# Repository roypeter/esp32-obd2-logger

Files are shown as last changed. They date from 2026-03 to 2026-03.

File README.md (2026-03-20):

# ESP32 OBD2 CAN Logger

A DIY OBD2 data logger built with an ESP32. Reads live engine data over CAN bus, logs to CSV (SD card or internal flash), shows live values on a small OLED display, and serves a real-time web dashboard over WiFi.

> **Note:** Only tested on a **2020 Tata Nexon 1.2L Turbo Petrol (6-speed manual)**. Should work on any car with standard OBD2 over CAN (ISO 15765-4, 500 kbps).

## Using AI to review your driving data

Download the CSV from the WiFi dashboard and upload it to an AI model like **Claude** or **Gemini Pro**. You can ask questions like:

- "How is the turbo performance?"
- "Review if all sensors are working correctly and flag any issues"
- "Is the fuel trim normal or is the engine running rich/lean?"
- "Any signs of engine problems based on this data?"

The AI can analyze thousands of rows of sensor data in seconds and give you a plain-English health report of your car.

Here's an example report generated from a real driving session:

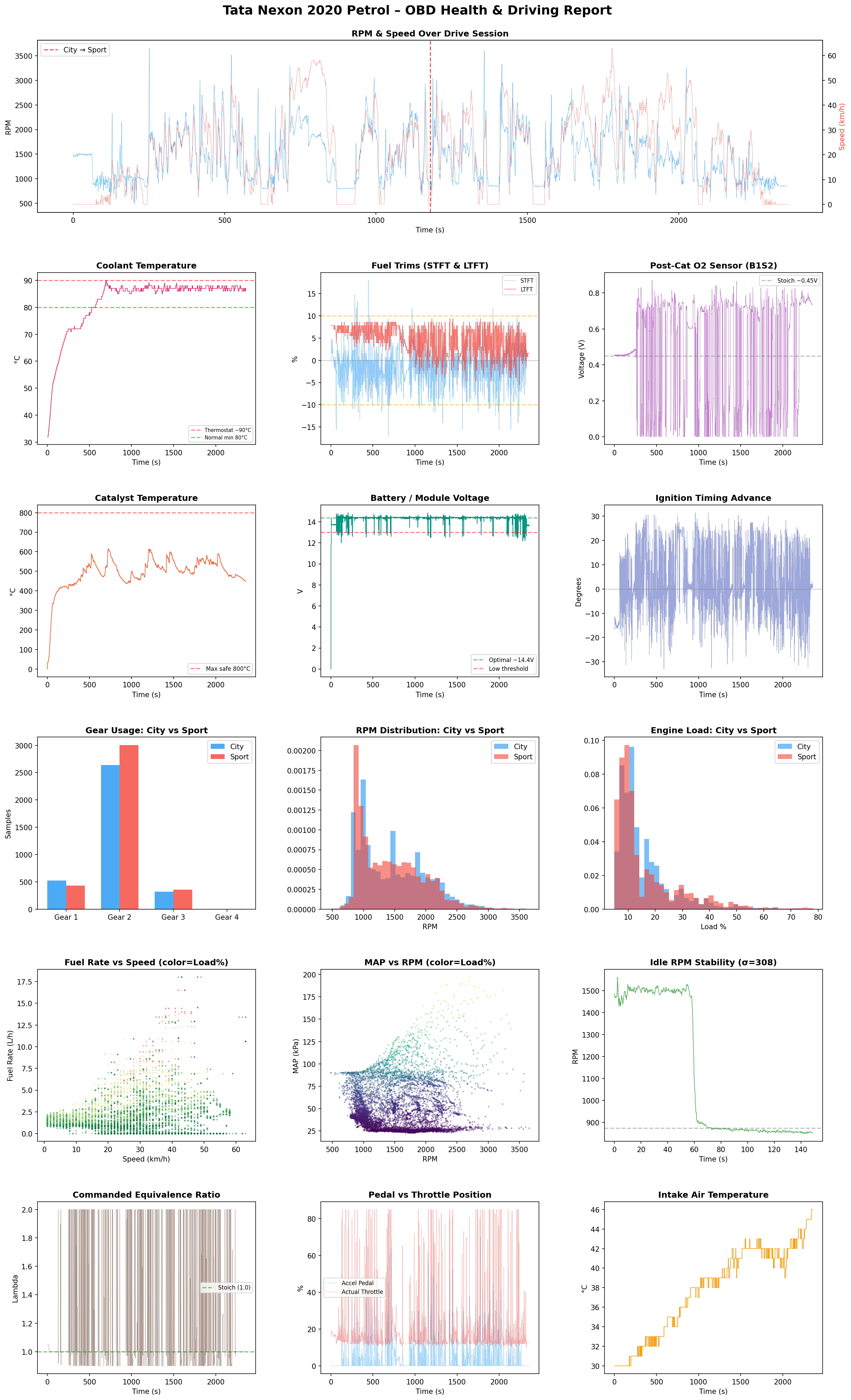
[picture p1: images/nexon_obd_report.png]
OBD Health & Driving Report


## What it does

- Reads **30+ OBD2 PIDs**: RPM, speed, coolant temp, oil temp, MAP, IAT, engine load, timing advance, throttle, accelerator pedal, fuel trims, O2 sensors, catalyst temp, fuel rate, voltage, and more
- **Logs to CSV** at ~4 Hz with automatic session numbering — SD card preferred, falls back to ESP32 internal flash (LittleFS) if no SD card is present
- **OLED display** (optional) — rotates between live data, running averages, and session stats (max boost, trip distance, fuel economy)
- **WiFi dashboard** — connect your phone to see live gauges, download CSV files, and check PID status
- **Smart polling** — fast-changing PIDs polled at ~4 Hz, slow-changing PIDs at ~1 Hz
- **Auto-disables unsupported PIDs** — if a PID times out 10 times in a row, it stops polling it
- **Estimates current gear** from RPM/speed ratio (calibrated for Nexon 6MT gearbox)

## Parts list

| Part | Notes |
|---|---|
| [ESP32 Dev Board](https://robocraze.com/products/esp32-development-board) | Any ESP32-WROOM-32 dev board works |
| [TJA1050 CAN Module](https://robu.in/product/tja1050-can-module-green-board/) | 5V module — needs a voltage divider on RX (see wiring). A 3.3V CAN module (e.g. SN65HVD230) is easier if you can find one |
| [Micro SD Card Module](https://robu.in/product/micro-sd-card-module/) *(optional)* | HW-125 with onboard level shifter. Power from 5V. Without it, logs to ESP32 internal flash (~1.5 MB) |
| [0.96" SSD1306 OLED Display](https://robu.in/product/0-96-oled-display-module-spi-i2c-128x64-7-pin-blue/) *(optional)* | 128x64, I2C. The logger works without it |
| [OBD2 Extension Cable](https://www.amazon.in/dp/B0F6NGFKQT) | 16-pin male to female — splice into the male end for CAN High/Low |
| SD Card *(optional)* | I use a SanDisk Ultra 64GB. Any size works — CSV files are small |
| Jumper wires, solder, etc. | -- |

I mostly order from [robocraze.com](https://robocraze.com) or [robu.in](https://robu.in) — check both for availability and pricing.

## Wiring

Full wiring details below.

### ESP32 to TJA1050 CAN Module

```
ESP32 GPIO5  ──────────────────  TJA1050 TXD
ESP32 GPIO4  ──┬── 1kΩ ────────  TJA1050 RXD     (voltage divider: 5V → 3.4V)
               └── 2.2kΩ ─────  GND
ESP32 5V     ──────────────────  TJA1050 VCC
ESP32 GND    ──────────────────  TJA1050 GND
```

> If using a 3.3V CAN transceiver (e.g. SN65HVD230), skip the voltage divider and connect RX directly.

### TJA1050 to OBD2 Connector

```
TJA1050 CANH  ──  OBD2 Pin 6  (CAN High)
TJA1050 CANL  ──  OBD2 Pin 14 (CAN Low)
TJA1050 GND     ──  OBD2 Pin 4 or 5  (Chassis/Signal Ground)
```

### ESP32 to SD Card Module (HW-125) — optional

```
ESP32 GND    ──  GND
ESP32 5V     ──  VCC
ESP32 GPIO19 ──  MISO
ESP32 GPIO23 ──  MOSI
ESP32 GPIO18 ──  SCK
ESP32 GPIO15 ──  CS
```

> If no SD card module is connected, the logger automatically falls back to the ESP32's internal flash (LittleFS, ~1.5 MB). This gives you roughly 30 minutes of logging. Download the CSV over WiFi before it fills up.

### ESP32 to OLED Display (optional)

```
ESP32 GND    ──  GND
ESP32 3.3V   ──  VCC
ESP32 GPIO21 ──  SDA
ESP32 GPIO22 ──  SCL
```

## Flashing

### Prerequisites

1. Install the [Arduino IDE](https://www.arduino.cc/en/software) (v2.x recommended)
2. Add ESP32 board support:
   - Go to **Tools → Board → Boards Manager**, search "esp32", install **esp32 by Espressif Systems**
3. Install required libraries via **Sketch → Include Library → Manage Libraries**:
   - `Adafruit SSD1306`
   - `Adafruit GFX Library`

   (SD, SPI, Wire, WiFi, and WebServer are included with the ESP32 board package.)

### Upload

1. Connect the ESP32 via USB
2. Open `main/main.ino` in Arduino IDE
3. Select your board: **Tools → Board → ESP32 Dev Module**
4. Select the correct port: **Tools → Port**
5. Click **Upload**

## Usage

### 1. Power up

Plug the ESP32 into the car's USB port (or a USB power bank for bench testing). The OBD2 extension cable connects to the car's OBD2 port under the dashboard.

On startup, the OLED (if connected) shows:
```
Nexon CAN Logger

SD  Session #1            (or "LittleFS  Session #1" if no SD card)
Total: 59000 MB
Used:  12 MB
Free:  58988 MB
```

The serial monitor (115200 baud) shows the same info plus CAN bus init status.

### 2. Connect to the WiFi dashboard

1. On your phone, connect to WiFi network: **`obd2logger`** (password: `logger@ka01`)
2. Open a browser and go to **`http://192.168.4.1`**

You'll see a live dashboard with all the gauges updating every second:

- **Dashboard** (`/`) — live gauges for all PIDs, storage bar, download/session links
- **All Sessions** (`/sessions`) — list of all logged sessions with download and delete options
- **Download Current** (`/download`) — download the active session CSV
- **Debug Log** (`/log`) — ring buffer of recent debug messages
- **PID Status** (`/timeouts`) — see which PIDs are responding and which got auto-disabled

### 3. Data logging

Logging starts automatically on boot. Each power cycle creates a new session file (`s001.csv`, `s002.csv`, ...). With an SD card, files are stored in `/data/` on the card. Without one, they go to the ESP32's internal flash (LittleFS).

CSV columns:
```
Timestamp_ms, RPM, Speed_kmh, Coolant_C, OilTemp_C, MAP_kPa, IAT_C,
Load_pct, TimingAdv_deg, Throttle_pct, AccelPedal_pct, CmdThrottle_pct,
DemandTorque_pct, ActualTorque_pct, STFT_pct, LTFT_pct, Baro_kPa,
O2S2_V, O2S2_STFT_pct, CmdEquivRatio, CatalystTemp_C, O2_SecLTFT_pct,
Gear, FuelLevel_pct, FuelRate_Lph, ModuleVoltage_V, AmbientTemp_C,
RefTorque_Nm, O2S1_Lambda, O2S1_Current_mA, AbsLoad_pct, EvapPurge_pct
```

### 4. Serial monitor output

At 115200 baud, you'll see a continuous stream like:
```
RPM:850 Spd:0 Clt:82 Oil:78 MAP:33 IAT:42 Load:18% Tmg:6.5 Thr:14% ...
```

Plus periodic status:
```
[12345] TX:482 RX:391 RX_timeout:91
[12345] TWAI state:1 txErr:0 rxErr:0 txQ:0 rxQ:0
```

## Notes

- **SD card is optional.** If no SD card is found, the logger falls back to ESP32 internal flash (LittleFS, ~1.5 MB). That's roughly 30 minutes of logging at 4 Hz — download the CSV over WiFi before it fills up. If neither SD nor LittleFS can mount, the ESP32 won't start (nothing to log to).
- **OLED is optional.** If not connected, everything else works normally.
- **Not all PIDs will work on every car.** The logger auto-disables PIDs that your car's ECU doesn't support. Check the PID Status page (`/timeouts`) to see which ones your car responds to.
- **Gear estimation** is calibrated for the Nexon 1.2T 6-speed manual gearbox. If you're using a different car, you'll need to adjust the `GEAR_RATIO_MIN[]` and `GEAR_RATIO_MAX[]` arrays in the code.
- **WiFi range** is limited to a few meters — it's meant for use inside the car.

## 3D Printable Cases

If you are looking to enclose your logger components, check out the [3D Printable Cases](3dprint/README.md) provided in the `3dprint` folder. It includes basic housings for the ESP32, S3 module, and OLED display.

## License

This project is licensed under [CC BY-NC 4.0](https://creativecommons.org/licenses/by-nc/4.0/) — free to use, share, and modify for non-commercial purposes with attribution. No warranty.

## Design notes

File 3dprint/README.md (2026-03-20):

# 3D Printable Cases

These are 3D printable cases for:
- Housing both the ESP32 dev module and the S3 card module (both without header pins) in a single case. **Note:** This is a very basic case designed just to keep the modules inside, and it might not fit the specific dev board you are using.
- There is a case for a 0.91 inch OLED screen as well

**Note:** The cap of the case needs a bit of glue to keep it secure.

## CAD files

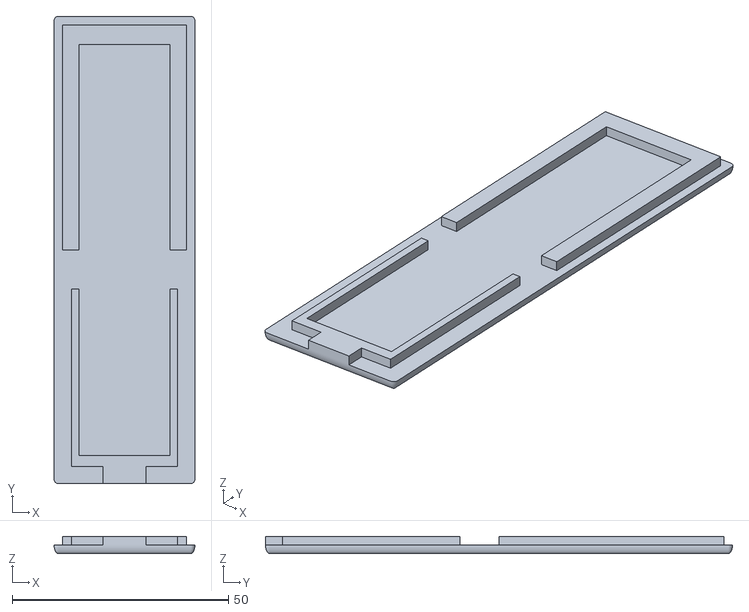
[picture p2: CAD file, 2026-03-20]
3dprint/obd2-case-top.stl
32.6 x 108.0 x 4.00

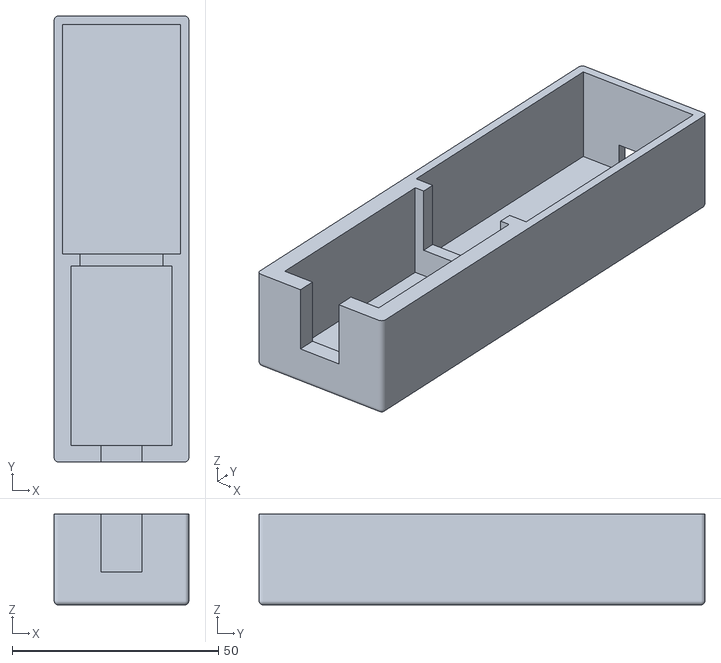
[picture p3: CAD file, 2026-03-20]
3dprint/obd2-case-base.stl
32.6 x 108.0 x 22.0

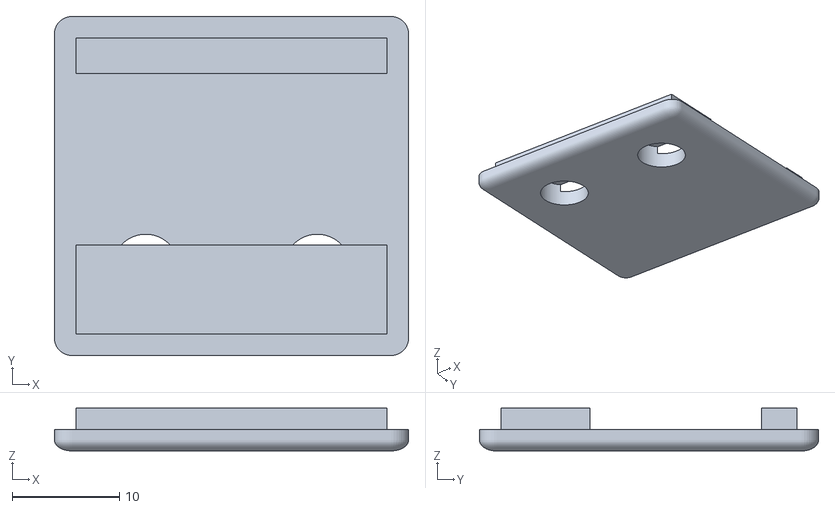
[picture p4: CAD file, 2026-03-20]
3dprint/oled-case-top.stl
33.0 x 31.6 x 4.00

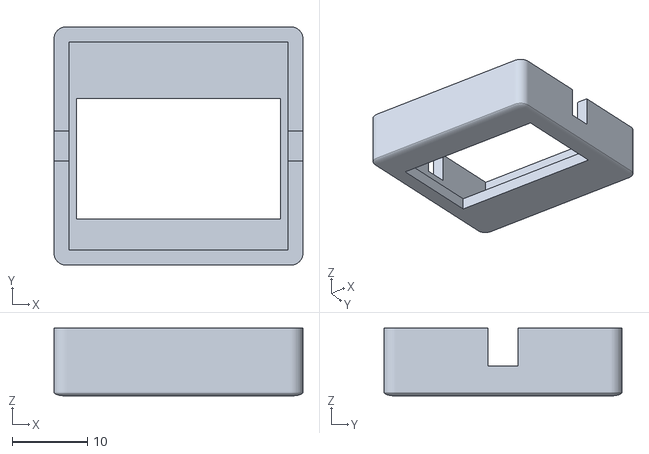
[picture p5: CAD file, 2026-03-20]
3dprint/oled-case-base.stl
33.0 x 31.6 x 9.00

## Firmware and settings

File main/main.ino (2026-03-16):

#include <Arduino.h>
#include <WiFi.h>
#include <WebServer.h>
#include <SD.h>
#include <LittleFS.h>
#include <SPI.h>
#include <Wire.h>
#include <Adafruit_GFX.h>
#include <Adafruit_SSD1306.h>

#define SD_CS 15
#define SCREEN_WIDTH 128
#define SCREEN_HEIGHT 64
#define OLED_ADDR 0x3C
#define OLED_UPDATE_MS 500

#include "driver/twai.h"

struct PidStats;

Adafruit_SSD1306 oled(SCREEN_WIDTH, SCREEN_HEIGHT, &Wire, -1);
unsigned long lastOledUpdate = 0;

// Storage abstraction — SD card preferred, LittleFS fallback
FS* storage = nullptr;
bool useSD = false;

uint64_t storageTotalBytes() {
  return useSD ? SD.totalBytes() : LittleFS.totalBytes();
}
uint64_t storageUsedBytes() {
  return useSD ? SD.usedBytes() : LittleFS.usedBytes();
}

// --- Configuration ---
const char* ssid = "obd2logger";
const char* password = "logger@ka01"; // Must be at least 8 characters

#define RX_PIN 4
#define TX_PIN 5
#define RESPONSE_TIMEOUT_MS 50
#define SLOW_POLL_RATIO 5  // 1 slow PID every 5 polls (pattern: F F F F S)

WebServer server(80);
SemaphoreHandle_t fsMutex;

// Fast PIDs — change rapidly during driving (~4Hz per PID)
const uint8_t fast_pids[] = {
  0x0C, 0x0D, 0x0B, 0x04, 0x0E, 0x47,  // RPM, Speed, MAP, Load, Timing, Throttle
  0x5A, 0x4C, 0x61, 0x62,               // Pedal, CmdThr, DemTorque, ActTorque
  0x06, 0x07, 0x15, 0x44, 0x56,         // STFT, LTFT, O2S2, CmdEq, SecLTFT
  0x5E,                                  // Fuel Rate
  0x34, 0x43                             // O2S1 WR Lambda+Current, Absolute Load
};
const int NUM_FAST = sizeof(fast_pids) / sizeof(fast_pids[0]);

// Slow PIDs — change slowly, polled less often (~1Hz per PID)
const uint8_t slow_pids[] = {
  0x05, 0x0F, 0x33,                     // Coolant, IAT, Baro
  0x3C, 0x5C, 0x2F,                     // CatTemp, Oil Temp, Fuel Level
  0x42, 0x46, 0x63,                     // Voltage, Ambient Temp, Ref Torque
  0x2E                                  // Commanded Evap Purge
};
const int NUM_SLOW = sizeof(slow_pids) / sizeof(slow_pids[0]);

// Per-PID timeout tracking and auto-disable
#define MAX_PIDS 32
#define PID_DISABLE_THRESHOLD 10  // disable after N consecutive timeouts
struct PidStats {
  uint8_t pid;
  unsigned long timeouts;
  unsigned long responses;
  uint8_t consecutiveTimeouts;
  bool disabled;
};
PidStats pidStats[MAX_PIDS];
int numTrackedPids = 0;

PidStats* getPidStats(uint8_t pid) {
  for (int i = 0; i < numTrackedPids; i++) {
    if (pidStats[i].pid == pid) return &pidStats[i];
  }
  if (numTrackedPids < MAX_PIDS) {
    PidStats* s = &pidStats[numTrackedPids++];
    s->pid = pid; s->timeouts = 0; s->responses = 0;
    s->consecutiveTimeouts = 0; s->disabled = false;
    return s;
  }
  return nullptr;
}

bool isPidDisabled(uint8_t pid) {
  PidStats* s = getPidStats(pid);
  return s && s->disabled;
}

// Response-driven polling state
bool requestPending = false;
unsigned long requestSentTime = 0;
uint8_t pendingPid = 0;
int pollCounter = 0;
int fastIndex = 0;
int slowIndex = 0;

// Latest values
int rpm = 0;
int speed_kmh = 0;
int coolant_temp = 0;
int manifold_kpa = 0;
int intake_temp = 0;
int engine_load = 0;
float timing_advance = 0;
int throttle_pos = 0;
int accel_pedal = 0;
int cmd_throttle = 0;
int demand_torque = 0;
int actual_torque = 0;
float short_fuel_trim = 0;
float long_fuel_trim = 0;
int baro_kpa = 0;
float o2_s2_voltage = 0;
float o2_s2_stft = 0;
float cmd_equiv_ratio = 0;
int catalyst_temp = 0;
float o2_secondary_ltft = 0;
int oil_temp = 0;
int fuel_level = 0;
float fuel_rate = 0;        // L/h
float module_voltage = 0;   // V
int ambient_temp = 0;       // °C
int ref_torque = 0;         // N·m
float o2s1_lambda = 0;      // O2S1 WR equivalence ratio (lambda)
float o2s1_current = 0;     // O2S1 WR current (mA)
float absolute_load = 0;    // Absolute load (%)
int evap_purge = 0;         // Commanded evap purge (%)
int estimated_gear = 0; // 0 = neutral/clutch, 1-6 = gear
unsigned long lastLog = 0;

// Session-based logging
int sessionNum = 0;
char sessionFile[24]; // e.g. "/data/s001.csv"
const char* CSV_HEADER = "Timestamp_ms,RPM,Speed_kmh,Coolant_C,OilTemp_C,MAP_kPa,IAT_C,Load_pct,TimingAdv_deg,Throttle_pct,AccelPedal_pct,CmdThrottle_pct,DemandTorque_pct,ActualTorque_pct,STFT_pct,LTFT_pct,Baro_kPa,O2S2_V,O2S2_STFT_pct,CmdEquivRatio,CatalystTemp_C,O2_SecLTFT_pct,Gear,FuelLevel_pct,FuelRate_Lph,ModuleVoltage_V,AmbientTemp_C,RefTorque_Nm,O2S1_Lambda,O2S1_Current_mA,AbsLoad_pct,EvapPurge_pct";

// Running averages for OLED stats page
float avgStft = 0, avgTiming = 0, avgMap = 0;
unsigned long avgSamples = 0;

// Session tracking for OLED page 3
int maxBoost = 0;
unsigned long sessionStartMs = 0;
float totalDistKm = 0;    // accumulated distance
float totalFuelL = 0;     // accumulated fuel consumed

// OLED page timing
#define OLED_STATS_INTERVAL 30000  // show stats every 30s
#define OLED_STATS_DURATION 5000   // show each stats page for 5s
unsigned long lastStatsShow = 0;
int oledStatsPage = 0;  // 0=live, 1=avgs, 2=session stats

// --- Debug ring buffer log ---
#define LOG_LINES 50
#define LOG_LINE_LEN 120
char logBuf[LOG_LINES][LOG_LINE_LEN];
int logIndex = 0;
unsigned long txCount = 0, rxCount = 0, rxTimeoutCount = 0;
unsigned long lastStatusLog = 0;

void addLog(const char* fmt, ...) {
  char* line = logBuf[logIndex % LOG_LINES];
  int off = snprintf(line, LOG_LINE_LEN, "[%lu] ", millis());
  va_list args;
  va_start(args, fmt);
  vsnprintf(line + off, LOG_LINE_LEN - off, fmt, args);
  va_end(args);
  Serial.println(line);
  logIndex++;
}

// Estimated RPM/Speed ratio boundaries for Nexon 1.2T petrol 6-speed manual.
// Calibrate these after a test drive by noting RPM at a steady speed in each gear.
// ratio = RPM / Speed_kmh
const float GEAR_RATIO_MIN[] = { 80,  42, 28, 20, 15, 12 }; // lower bound for gears 1-6
const float GEAR_RATIO_MAX[] = { 160, 79, 41, 27, 22, 17 }; // upper bound for gears 1-6

// Web server task running on Core 0
void webServerTask(void *parameter) {
  for (;;) {
    server.handleClient();
    vTaskDelay(1); // yield to WiFi stack on Core 0
  }
}

void updateStats() {
  avgSamples++;
  float n = (float)avgSamples;
  avgStft += (short_fuel_trim - avgStft) / n;
  avgTiming += (timing_advance - avgTiming) / n;
  avgMap += (manifold_kpa - avgMap) / n;

  if (manifold_kpa > maxBoost) maxBoost = manifold_kpa;

  // Accumulate distance and fuel (called every 500ms = OLED_UPDATE_MS)
  float dt_h = OLED_UPDATE_MS / 3600000.0;  // interval in hours
  totalDistKm += speed_kmh * dt_h;
  totalFuelL += fuel_rate * dt_h;
}

void drawOledLive() {
  oled.clearDisplay();
  oled.setTextColor(SSD1306_WHITE);

  // Row 1: RPM | IAT
  oled.setTextSize(2);
  oled.setCursor(0, 0);
  oled.print(rpm);
  oled.setCursor(80, 0);
  oled.print(intake_temp);

  // Row 2: TMG | MAP
  oled.setCursor(0, 22);
  oled.print(timing_advance, 1);
  oled.setCursor(80, 22);
  oled.print(manifold_kpa);

  // Row 3: CLT | LOAD
  oled.setCursor(0, 44);
  oled.print(coolant_temp);
  oled.setCursor(80, 44);
  oled.print(engine_load);

  oled.display();
}

void drawOledStats() {
  oled.clearDisplay();
  oled.setTextColor(SSD1306_WHITE);
  oled.setTextSize(2);

  oled.setCursor(0, 0);
  oled.print("S ");
  oled.print(avgStft, 1);

  oled.setCursor(0, 22);
  oled.print("T ");
  oled.print(avgTiming, 1);

  oled.setCursor(0, 44);
  oled.print("M ");
  oled.print(avgMap, 0);

  oled.display();
}

void drawOledSession() {
  oled.clearDisplay();
  oled.setTextColor(SSD1306_WHITE);
  oled.setTextSize(2);

  // Max boost
  oled.setCursor(0, 0);
  oled.print(maxBoost);

  // Session time hh:mm
  unsigned long elapsed = (millis() - sessionStartMs) / 1000;
  int hh = elapsed / 3600;
  int mm = (elapsed % 3600) / 60;
  oled.setCursor(0, 22);
  char timeBuf[8];
  snprintf(timeBuf, sizeof(timeBuf), "%02d:%02d", hh, mm);
  oled.print(timeBuf);

  // Fuel mileage km/L
  oled.setCursor(0, 44);
  if (totalFuelL > 0.01) {
    oled.print(totalDistKm / totalFuelL, 1);
  } else {
    oled.print("--");
  }

  oled.display();
}

void updateOled() {
  updateStats();

  unsigned long now = millis();

  // Page rotation: 0=live, 1=avgs page, 2=session page
  if (oledStatsPage > 0) {
    unsigned long pageStart = lastStatsShow + (oledStatsPage - 1) * OLED_STATS_DURATION;
    if (now - pageStart >= OLED_STATS_DURATION) {
      oledStatsPage++;
      if (oledStatsPage > 2) oledStatsPage = 0;  // back to live
    }
    if (oledStatsPage == 1) { drawOledStats(); return; }
    if (oledStatsPage == 2) { drawOledSession(); return; }
  }

  if (now - lastStatsShow >= OLED_STATS_INTERVAL && avgSamples > 0) {
    oledStatsPage = 1;
    lastStatsShow = now;
    drawOledStats();
    return;
  }

  drawOledLive();
}

void setup() {
  Serial.begin(115200);
  
  // 1. Initialize storage (SD card preferred, LittleFS fallback) and mutex
  fsMutex = xSemaphoreCreateMutex();

  bool sdOk = SD.begin(SD_CS);
  if (sdOk) {
    storage = &SD;
    useSD = true;
    addLog("SD card mounted OK — Size: %llu MB", SD.cardSize() / (1024 * 1024));
  } else {
    addLog("SD card not found, trying internal flash (LittleFS)");
    if (LittleFS.begin(true)) {  // true = format on first use
      storage = &LittleFS;
      addLog("LittleFS mounted OK (~1.5 MB available, logs fill up fast)");
    } else {
      addLog("LittleFS mount FAILED — no storage available");
    }
  }

  if (storage) {
    addLog("Storage: %llu KB used / %llu KB total",
           storageUsedBytes() / 1024, storageTotalBytes() / 1024);

    // Create data folder if it doesn't exist
    if (!storage->exists("/data")) storage->mkdir("/data");

    // Read session counter, increment, and save
    File sf = storage->open("/data/session.txt", "r");
    if (sf) {
      sessionNum = sf.parseInt();
      sf.close();
    }
    sessionNum++;
    sf = storage->open("/data/session.txt", "w");
    if (sf) { sf.print(sessionNum); sf.close(); }
    snprintf(sessionFile, sizeof(sessionFile), "/data/s%03d.csv", sessionNum);
    addLog("Session %d -> %s", sessionNum, sessionFile);

    // Create new session CSV with headers
    File file = storage->open(sessionFile, "w");
    if (file) { file.println(CSV_HEADER); file.close(); }
  }

  // 2. Initialize OLED and show SD card status
  if (oled.begin(SSD1306_SWITCHCAPVCC, OLED_ADDR)) {
    Wire.setClock(400000);
    addLog("OLED init OK");
    oled.clearDisplay();
    oled.setTextColor(SSD1306_WHITE);
    oled.setTextSize(1);
    oled.setCursor(0, 0);
    oled.println("Nexon CAN Logger");
    oled.println();
    if (storage) {
      uint64_t totalKB = storageTotalBytes() / 1024;
      uint64_t usedKB = storageUsedBytes() / 1024;
      uint64_t freeKB = totalKB - usedKB;
      oled.printf("%s  Session #%d\n", useSD ? "SD" : "LittleFS", sessionNum);
      if (totalKB >= 1024) {
        oled.printf("Total: %llu MB\n", totalKB / 1024);
        oled.printf("Used:  %llu MB\n", usedKB / 1024);
        oled.printf("Free:  %llu MB", freeKB / 1024);
      } else {
        oled.printf("Total: %llu KB\n", totalKB);
        oled.printf("Used:  %llu KB\n", usedKB);
        oled.printf("Free:  %llu KB", freeKB);
      }
    } else {
      oled.println("Storage: NONE");
    }
    oled.display();
    delay(3000);
  } else {
    addLog("OLED init FAILED");
  }

  if (!storage) return;

  sessionStartMs = millis();

  // 2. Initialize WiFi Access Point
  WiFi.softAP(ssid, password);
  addLog("WiFi AP started, IP: %s", WiFi.softAPIP().toString().c_str());

  // 3. Set Up Web Server Routes

  // Reusable gauge macro for dashboard
  #define GAUGE(label, id, color) \
    "<div style='background:#16213e;border-radius:12px;padding:20px 30px;min-width:120px;'>" \
    "<div style='font-size:0.9em;color:#aaa;'>" label "</div>" \
    "<div id='" id "' style='font-size:2.2em;font-weight:bold;color:" color ";'>--</div></div>"
  #define GAUGE_UNIT(label, id, color, unit) \
    "<div style='background:#16213e;border-radius:12px;padding:20px 30px;min-width:120px;'>" \
    "<div style='font-size:0.9em;color:#aaa;'>" label "</div>" \
    "<div><span id='" id "' style='font-size:2.2em;font-weight:bold;color:" color ";'>--</span>" \
    "<span style='color:#aaa;'> " unit "</span></div></div>"
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
void loop() {
  // --- Step 1: Send next request if none pending ---
  if (!requestPending) {
    uint8_t nextPid = getNextPid();
    sendObd2Request(nextPid);
  }

  // --- Step 2: Timeout pending request after RESPONSE_TIMEOUT_MS ---
  if (requestPending && (millis() - requestSentTime >= RESPONSE_TIMEOUT_MS)) {
    requestPending = false;
    rxTimeoutCount++;
    PidStats* s = getPidStats(pendingPid);
    if (s) {
      s->timeouts++;
      s->consecutiveTimeouts++;
      if (!s->disabled && s->consecutiveTimeouts >= PID_DISABLE_THRESHOLD) {
        s->disabled = true;
        addLog("PID 0x%02X disabled after %d timeouts", s->pid, PID_DISABLE_THRESHOLD);
      }
    }
  }

  // --- Step 3: Try to receive a response ---
  twai_message_t rx_msg;
  esp_err_t rxErr = twai_receive(&rx_msg, pdMS_TO_TICKS(5));
  if (rxErr == ESP_OK) {
    rxCount++;
    if (rx_msg.identifier == 0x7E8 && rx_msg.data[1] == 0x41) {
      parseObd2Response(rx_msg);
      PidStats* s = getPidStats(rx_msg.data[2]);
      if (s) { s->responses++; s->consecutiveTimeouts = 0; }
      if (requestPending && rx_msg.data[2] == pendingPid) {
        requestPending = false;
      }
    }
  }

  // --- Step 4: Estimate gear and log at 250ms interval ---
  if (millis() - lastLog >= 250) {
    lastLog = millis();

    // Estimate gear from RPM/Speed ratio
    if (speed_kmh >= 5 && rpm > 0) {
      float ratio = (float)rpm / speed_kmh;
      estimated_gear = 0;
      for (int i = 0; i < 6; i++) {
        if (ratio >= GEAR_RATIO_MIN[i] && ratio <= GEAR_RATIO_MAX[i]) {
          estimated_gear = i + 1;
          break;
        }
      }
    } else {
      estimated_gear = 0; // Neutral / clutch / stationary
    }

    // Periodic debug status log (every 5s)
    if (millis() - lastStatusLog >= 5000) {
      lastStatusLog = millis();
      addLog("TX:%lu RX:%lu RX_timeout:%lu", txCount, rxCount, rxTimeoutCount);
      twai_status_info_t status;
      if (twai_get_status_info(&status) == ESP_OK) {
        addLog("TWAI state:%d txErr:%lu rxErr:%lu txQ:%lu rxQ:%lu",
               status.state, status.tx_error_counter, status.rx_error_counter,
               status.msgs_to_tx, status.msgs_to_rx);
      }
    }

    unsigned long timestamp = millis();

    uint64_t freeBytes = storageTotalBytes() - storageUsedBytes();
    if (freeBytes > 512) {
      if (xSemaphoreTake(fsMutex, pdMS_TO_TICKS(50))) {
        File file = storage->open(sessionFile, "a");
        if (file) {
          file.printf("%lu,%d,%d,%d,%d,%d,%d,%d,%.1f,%d,%d,%d,%d,%d,%.1f,%.1f,%d,%.3f,%.1f,%.3f,%d,%.1f,%d,%d,%.1f,%.2f,%d,%d,%.3f,%.2f,%.1f,%d\n",
            timestamp, rpm, speed_kmh, coolant_temp, oil_temp, manifold_kpa, intake_temp, engine_load,
            timing_advance, throttle_pos, accel_pedal, cmd_throttle, demand_torque, actual_torque,
            short_fuel_trim, long_fuel_trim, baro_kpa, o2_s2_voltage, o2_s2_stft,
            cmd_equiv_ratio, catalyst_temp, o2_secondary_ltft, estimated_gear, fuel_level,
            fuel_rate, module_voltage, ambient_temp, ref_torque,
            o2s1_lambda, o2s1_current, absolute_load, evap_purge);
          file.close();
        }
        xSemaphoreGive(fsMutex);
      }
    } else {
      Serial.println("WARNING: Storage full! Logging stopped. Download CSV and clear data.");
    }

    Serial.printf("RPM:%d Spd:%d Clt:%d Oil:%d MAP:%d IAT:%d Load:%d%% Tmg:%.1f Thr:%d%% Pedal:%d%% CmdThr:%d%% DmTq:%d%% AcTq:%d%% STFT:%.1f LTFT:%.1f Baro:%d O2S2:%.3fV/%.1f%% CmdEq:%.3f Cat:%dC SecLTFT:%.1f Gear:%d Fuel:%d%% FRate:%.1f Volt:%.2f Amb:%d RefTq:%d Lam:%.3f O2mA:%.2f AbsLd:%.1f Evap:%d%%\n",
                   rpm, speed_kmh, coolant_temp, oil_temp, manifold_kpa, intake_temp, engine_load,
                   timing_advance, throttle_pos, accel_pedal, cmd_throttle, demand_torque,
                   actual_torque, short_fuel_trim, long_fuel_trim, baro_kpa,
                   o2_s2_voltage, o2_s2_stft,
                   cmd_equiv_ratio, catalyst_temp, o2_secondary_ltft, estimated_gear, fuel_level,
                   fuel_rate, module_voltage, ambient_temp, ref_torque,
                   o2s1_lambda, o2s1_current, absolute_load, evap_purge);

    // Update OLED display every 500ms
    if (millis() - lastOledUpdate >= OLED_UPDATE_MS) {
      lastOledUpdate = millis();
      updateOled();
    }
  }
}

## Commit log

2026-03-16 Initial commit
    ESP32 OBD2 CAN logger
2026-03-16 Fix storage-related messages for SD/LittleFS dual support
    - mkdir /data now runs for both SD and LittleFS
    - "SD card full" warning updated to generic "Storage full"
    [main.ino]
2026-03-20 docs: add 3D print cases README and link in main README
2026-03-20 Add 3D print cases
    [obd2-case-base.stl, obd2-case-top.stl, oled-case-base.stl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]
